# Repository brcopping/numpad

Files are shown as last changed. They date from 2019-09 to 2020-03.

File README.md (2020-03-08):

# numpad PCB
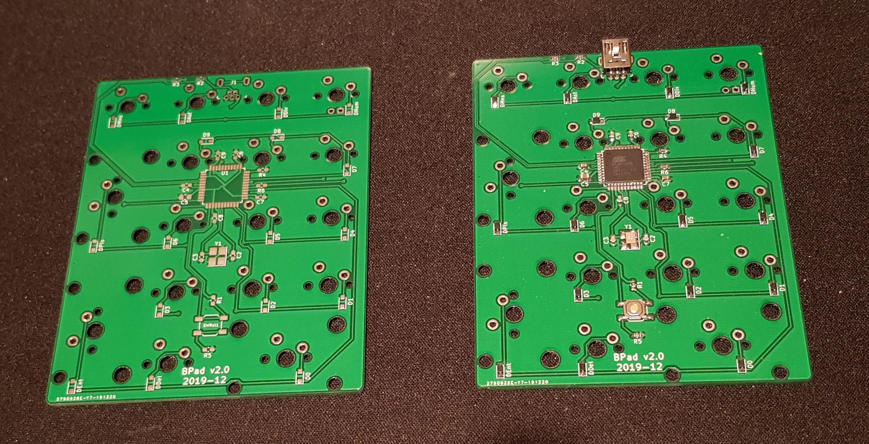
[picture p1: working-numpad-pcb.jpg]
working numpad PCB


I am following MrKeeb's and Gondolindrin's video series [PCB from Scratch with Gondo](https://youtu.be/Nk0egpDFqRA) and [ai03's guides](https://wiki.ai03.me/) to create my own numpad.

The layout is a standard numpad which can be seen here on [keyboard layout editor](http://www.keyboard-layout-editor.com/#/gists/febd745a52b943ce2c9e8b8bd37d3d38)

I created a rough case design ([main body](https://www.tinkercad.com/things/3bGqK5EBuhx) & [high profile rim](https://www.tinkercad.com/things/5EjXz9Ort4S)) for this PCB on tinkercad, it will take a [lazercut metal plate](https://github.com/brcopping/numpad/blob/master/Swill-Switch-Layer.dxf) for switch mounting. 

To hold the case together I used M3 nuts and bolts, 35mm for the back and 25mm for the front (all 4 protrude too much, so probably 33mm and 22mm would be better if attainable. Will cut mine down when i get a chance)

Numpad firmware added to [my QMK fork on git](https://github.com/brcopping/qmk_firmware). To genreate the firmware file run:
`make handwired/ben18:default`

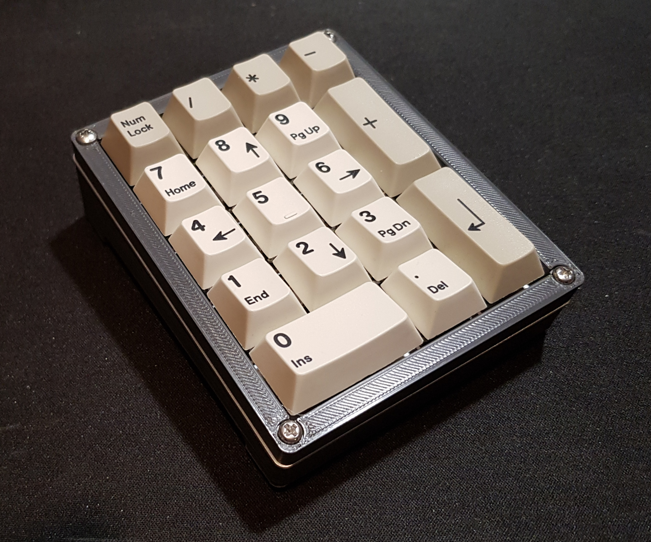
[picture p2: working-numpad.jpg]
working numpad


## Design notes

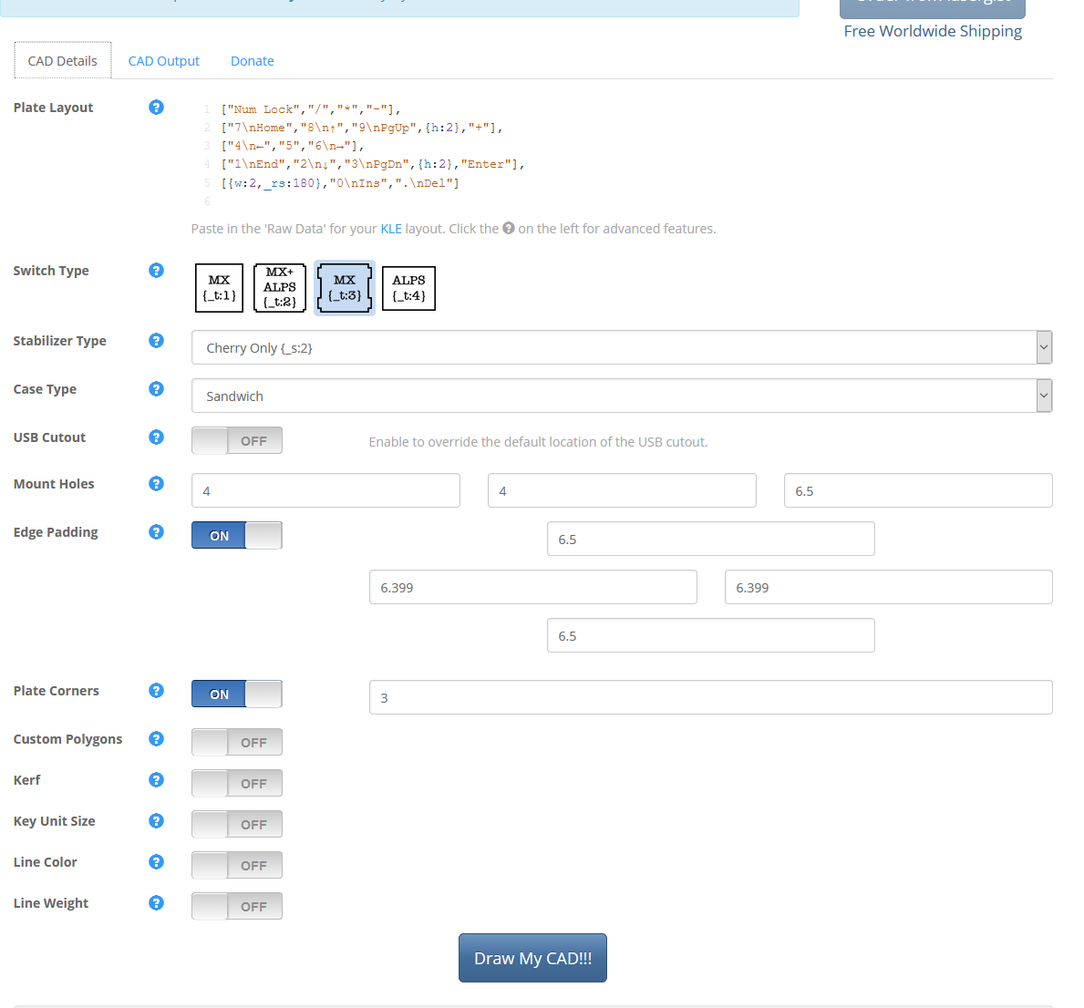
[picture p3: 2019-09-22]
Swill-Settings.PNG

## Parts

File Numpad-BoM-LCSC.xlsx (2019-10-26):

LCSC Part Number | Manufacture Part Number | Manufacturer | Customer NO. | Package | Description | RoHS | Order Qty. | Min\Mult Order Qty. | Unit Price | Order Price
C23138 | 0603WAF3300T5E | Uniroyal Elec |  | 0603 | Chip Resistor - Surface Mount 330Ohms ±1% 1/10W 0603 RoHS | Yes | 100 | 100\100 | $0.0009 | $0.09
C60580 | 1N4148WS-7-F | Diodes Incorporated |  | SOD-323 | Switching Diode 75V 150mA 1.25V @ 150mA 4ns SOD-323 RoHS | Yes | 150 | 50\50 | $0.013 | $1.95
C91701 | 0603CG220J500NT | Guangdong Fenghua Advanced Tech |  | 0603 | Multilayer Ceramic Capacitors MLCC - SMD/SMT 22pF 50V 0603 RoHS | Yes | 100 | 100\100 | $0.0028 | $0.28
C92584 | K2-1187SQ-A4SW-06 | Korean Hroparts Elec |  | SMD | Tactile Switches SPST-NO 5.20mm x 5.20mm 1.50mm 50mA @ 12VDC SMD RoHS | Yes | 10 | 10\10 | $0.0471 | $0.48
C103199 | RTT031002FTP | RALEC |  | 0603 | Chip Resistor - Surface Mount 10KOhms ±1% 1/10W 0603 RoHS | Yes | 100 | 100\100 | $0.0009 | $0.09
C119027 | 0603B104J500CT | Walsin Tech Corp |  | 0603 | Multilayer Ceramic Capacitors MLCC - SMD/SMT 100nF 50V 0603 RoHS | Yes | 50 | 50\50 | $0.0061 | $0.31
C141872 | 0603X105K500 | Walsin Tech Corp |  | 0603 | Multilayer Ceramic Capacitors MLCC - SMD/SMT 1uF 50V 0603 RoHS | Yes | 20 | 20\20 | $0.0176 | $0.36
C174301 | RS-03K22R0FT | Guangdong Fenghua Advanced Tech |  | 0603 | Chip Resistor - Surface Mount 22Ohms ±1% 1/10W 0603 RoHS | Yes | 100 | 100\100 | $0.0009 | $0.09
C280078 | M16000c516 | ZheJiang East Crystal Elec |  | SMD-3225-4P | SMD Crystal Resonators 16MHz ±10ppm SMD-3225-4P RoHS | Yes | 5 | 5\5 | $0.1155 | $0.58
C296082 | 0805X475K500CT | Walsin Tech Corp |  | 0805 | Multilayer Ceramic Capacitors MLCC - SMD/SMT 4.7uF 50V 0805 RoHS | Yes | 10 | 5\5 | $0.0647 | $0.65
C429849 | 0548190519 | MOLEX |  | Through Hole | Audio & Video Connectors Through Hole RoHS | Yes | 3 | 1\1 | $1.4621 | $4.39

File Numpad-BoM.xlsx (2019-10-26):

C2 C3 | 2 | 22pF | Capacitor_SMD:C_0603_1608Metric_Pad1.05x0.95mm_HandSolder | https://www.digikey.co.uk/product-detail/en/avx-corporation/06035A220JAT2A/478-1167-1-ND/564199
C4 | 1 | 1uF | Capacitor_SMD:C_0603_1608Metric_Pad1.05x0.95mm_HandSolder | https://www.digikey.co.uk/product-detail/en/CC0805JKX7R9BB105/311-3498-1-ND/7164519/?itemSeq=306989339 | 805
C5 | 1 | 4.7uF | Capacitor_SMD:C_0603_1608Metric_Pad1.05x0.95mm_HandSolder | https://www.digikey.co.uk/product-detail/en/samsung-electro-mechanics/CL21A475KBQNNNE/1276-1248-1-ND/3889334 | 805
C1 C8 C7 C6 C9 | 5 | 0.1uF | Capacitor_SMD:C_0603_1608Metric_Pad1.05x0.95mm_HandSolder | https://www.digikey.co.uk/product-detail/en/CL10B104JB8NNNC/1276-1033-1-ND/3889119/?itemSeq=306988917
DNum1 DDiv1 DAst1 D7 D8 D9 D4 D5 D6 D1 D2 D3 DEnt1 DDel1 D0 DMns1 DPls1 DMns2 | 18 | 1N4148W | Diode_SMD:D_SOD-323_HandSoldering | https://www.digikey.co.uk/product-detail/en/1N4148WX-TP/1N4148WXTPMSCT-ND/717312
J1 | 1 | USB_B_Mini | digikey-kicad-library:USB_Mini_B_Female_548190519 | https://www.digikey.co.uk/product-detail/en/molex/0548190519/WM17115-ND/773802
R1 R4 | 2 | 10k | Resistor_SMD:R_0603_1608Metric_Pad1.05x0.95mm_HandSolder | https://www.digikey.co.uk/product-detail/en/rohm-semiconductor/ESR03EZPF1002/RHM10KADCT-ND/1983753
R2 R3 | 2 | 22 | Resistor_SMD:R_0603_1608Metric_Pad1.05x0.95mm_HandSolder | https://www.digikey.co.uk/product-detail/en/vishay-dale/CRCW060322R0JNEAHP/541-22SACT-ND/2222801
R5 | 1 | 330 | Resistor_SMD:R_0603_1608Metric_Pad1.05x0.95mm_HandSolder | https://www.digikey.co.uk/product-detail/en/yageo/RC0603FR-07330RL/311-330HRCT-ND/730109
SW0 | 1 | 0 | AcheronMX:MX200R
SW1 | 1 | 1 | AcheronMX:MX100
SW2 | 1 | 2 | AcheronMX:MX100
SW3 | 1 | 3 | AcheronMX:MX100
SW4 | 1 | 4 | AcheronMX:MX100
SW5 | 1 | 5 | AcheronMX:MX100
SW6 | 1 | 6 | AcheronMX:MX100
SW7 | 1 | 7 | AcheronMX:MX100
SW8 | 1 | 8 | AcheronMX:MX100
SW9 | 1 | 9 | AcheronMX:MX100
SWAst1 | 1 | * | AcheronMX:MX100
SWDel1 | 1 | Del | AcheronMX:MX100
SWDiv1 | 1 | / | AcheronMX:MX100
SWEnt1 | 1 | Ent | AcheronMX:MX200VR
SWMns1 | 1 | -/Bsp | AcheronMX:MX100
SWMns2 | 1 | - | AcheronMX:MX100
SWNum1 | 1 | Num | AcheronMX:MX100
SWPls1 | 1 | + | AcheronMX:MX200VR
SWPls2 | 1 | + | AcheronMX:MX100
SWRst1 | 1 | SW_Push | AcheronHardware:smdPushBtn | https://www.digikey.co.uk/product-detail/en/PTS525SM15SMTR2+LFS/CKN9104DKR-ND/1853734/?itemSeq=306989920
U1 | 1 | ATmega32U4-AU | Package_QFP:TQFP-44_10x10mm_P0.8mm
Y1 | 1 | 16MHz | Crystal:Crystal_SMD_3225-4Pin_3.2x2.5mm_HandSoldering | https://www.digikey.co.uk/product-detail/en/ndk-america-inc/NX3225SA-16.000M-STD-CSR-1/644-1049-1-ND/1128921

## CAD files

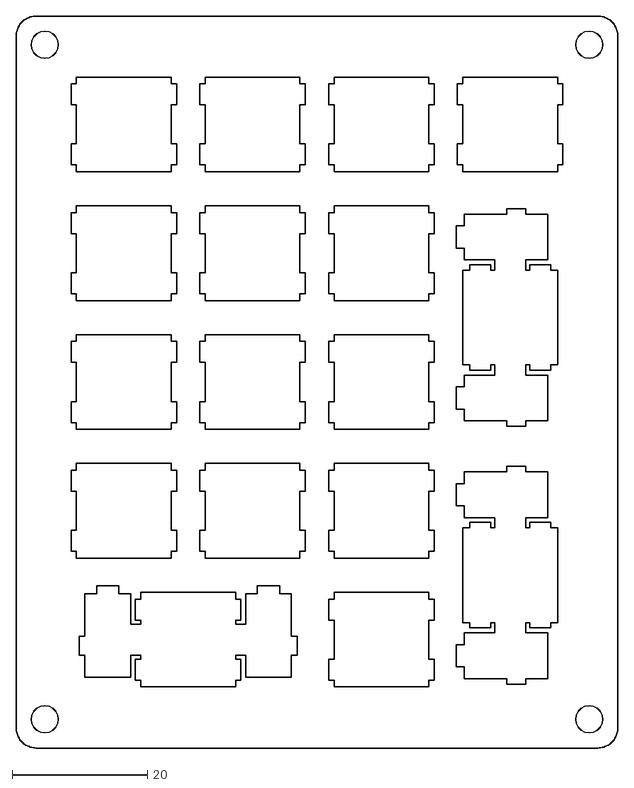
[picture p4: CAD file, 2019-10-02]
Swill-Switch-Layer.dxf
89.0 x 108.3

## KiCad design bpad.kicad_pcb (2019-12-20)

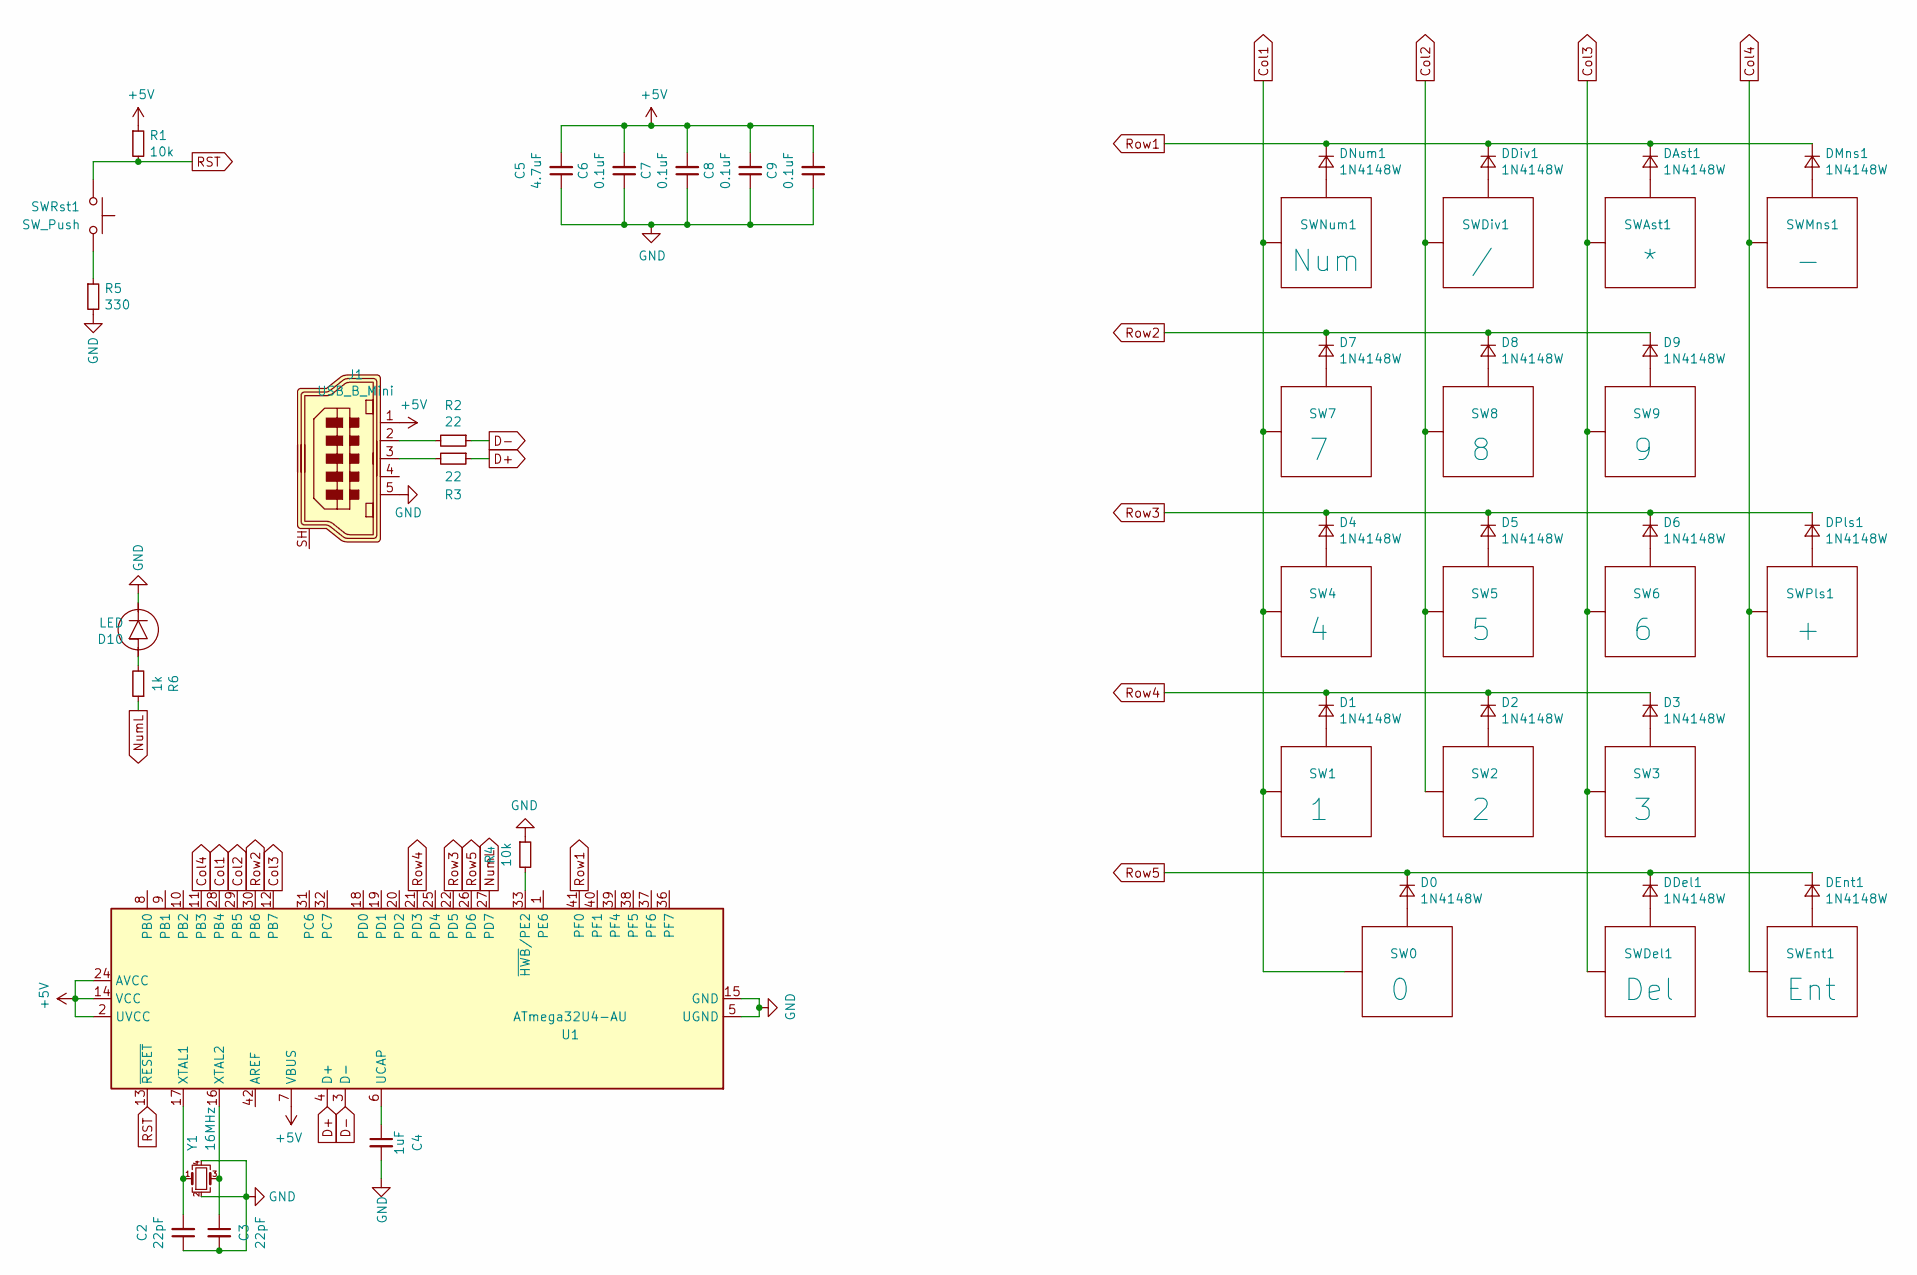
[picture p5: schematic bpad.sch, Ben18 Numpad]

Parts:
C2, C3: 22pF; C_0603_1608Metric_Pad1.05x0.95mm_HandSolder
C4: 1uF; C_0603_1608Metric_Pad1.05x0.95mm_HandSolder
C5: 4.7uF; C_0805_2012Metric_Pad1.15x1.40mm_HandSolder
C6, C7, C8, C9: 0.1uF; C_0603_1608Metric_Pad1.05x0.95mm_HandSolder
D0, D1, D2, D3, D4, D5, D6, D7, D8, D9: 1N4148W; D_SOD-323_HandSoldering
D10: LED; LED_THT_2.54mm
DAst1: 1N4148W; D_SOD-323_HandSoldering
DDel1: 1N4148W; D_SOD-323_HandSoldering
DDiv1: 1N4148W; D_SOD-323_HandSoldering
DEnt1: 1N4148W; D_SOD-323_HandSoldering
DMns1: 1N4148W; D_SOD-323_HandSoldering
DNum1: 1N4148W; D_SOD-323_HandSoldering
DPls1: 1N4148W; D_SOD-323_HandSoldering
J1: USB_B_Mini; USB_Mini_B_Female_548190519_top
R1, R4: 10k; R_0603_1608Metric_Pad1.05x0.95mm_HandSolder
R2, R3: 22; R_0603_1608Metric_Pad1.05x0.95mm_HandSolder
R5: 330; R_0603_1608Metric_Pad1.05x0.95mm_HandSolder
R6: 1k; R_0603_1608Metric_Pad1.05x0.95mm_HandSolder
SW0: 0; MX200R
SW1: 1; MX100
SW2: 2; MX100
SW3: 3; MX100
SW4: 4; MX100
SW5: 5; MX100
SW6: 6; MX100
SW7: 7; MX100
SW8: 8; MX100
SW9: 9; MX100
SWAst1: *; MX100
SWDel1: Del; MX100
SWDiv1: /; MX100
SWEnt1: Ent; MX200
SWMns1: -; MX100
SWNum1: Num; MX100
SWPls1: +; MX200
SWRst1: SW_Push; smdPushBtn
U1: ATmega32U4-AU; TQFP-44_10x10mm_P0.8mm
Y1: 16MHz; Crystal_SMD_3225-4Pin_3.2x2.5mm_HandSoldering

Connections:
+5V: C5.2, C6.2, C7.2, C8.2, C9.2, J1.1, R1.1, U1.2 (UVCC), U1.7 (VBUS), U1.14 (VCC), U1.24 (AVCC), U1.34 (VCC), U1.44 (AVCC)
Col1: SW0.1 (Col), SW1.1 (Col), SW4.1 (Col), SW7.1 (Col), SWNum1.1 (Col), U1.28 (PB4)
Col2: SW2.1 (Col), SW5.1 (Col), SW8.1 (Col), SWDiv1.1 (Col), U1.29 (PB5)
Col3: SW3.1 (Col), SW6.1 (Col), SW9.1 (Col), SWAst1.1 (Col), SWDel1.1 (Col), U1.12 (PB7)
Col4: SWEnt1.1 (Col), SWMns1.1 (Col), SWPls1.1 (Col), U1.11 (PB3)
D+: R3.1, U1.4 (D+)
D-: R2.1, U1.3 (D-)
GND: C2.1, C3.2, C4.2, C5.1, C6.1, C7.1, C8.1, C9.1, D10.K, J1.5, R4.1, R5.2, U1.5 (UGND), U1.15 (GND), U1.23 (GND), U1.35 (GND), U1.43 (GND), Y1.2, Y1.4
unnamed: C2.2, U1.17 (XTAL1), Y1.1
unnamed: C3.1, U1.16 (XTAL2), Y1.3
unnamed: C4.1, U1.6 (UCAP)
unnamed: D0.2 (A), SW0.2 (Row)
unnamed: D1.2 (A), SW1.2 (Row)
unnamed: D2.2 (A), SW2.2 (Row)
unnamed: D3.2 (A), SW3.2 (Row)
unnamed: D4.2 (A), SW4.2 (Row)
unnamed: D5.2 (A), SW5.2 (Row)
unnamed: D6.2 (A), SW6.2 (Row)
unnamed: D7.2 (A), SW7.2 (Row)
unnamed: D8.2 (A), SW8.2 (Row)
unnamed: D9.2 (A), SW9.2 (Row)
unnamed: D10.A, R6.2
unnamed: DAst1.2 (A), SWAst1.2 (Row)
unnamed 23: DDel1.2 (A), SWDel1.2 (Row); also elsewhere on the board
unnamed: DDiv1.2 (A), SWDiv1.2 (Row)
unnamed 25: DEnt1.2 (A), SWEnt1.2 (Row); also elsewhere on the board
unnamed: DMns1.2 (A), SWMns1.2 (Row)
unnamed: DNum1.2 (A), SWNum1.2 (Row)
unnamed 28: DPls1.2 (A), SWPls1.2 (Row); also elsewhere on the board
unnamed: J1.2, R2.2
unnamed: J1.3, R3.2
unnamed: R4.2, U1.33 (~HWB~/PE2)
unnamed: R5.1, SWRst1.2
NumL: R6.1, U1.27 (PD7)
RST: R1.2, SWRst1.1, U1.13 (~RESET)
Row1: DAst1.1 (K), DDiv1.1 (K), DMns1.1 (K), DNum1.1 (K), U1.41 (PF0)
Row2: D7.1 (K), D8.1 (K), D9.1 (K), U1.30 (PB6)
Row3: D4.1 (K), D5.1 (K), D6.1 (K), DPls1.1 (K), U1.22 (PD5); also elsewhere on the board
Row4: D1.1 (K), D2.1 (K), D3.1 (K), U1.21 (PD3)
Row5: D0.1 (K), DDel1.1 (K), DEnt1.1 (K), U1.26 (PD6); also elsewhere on the board

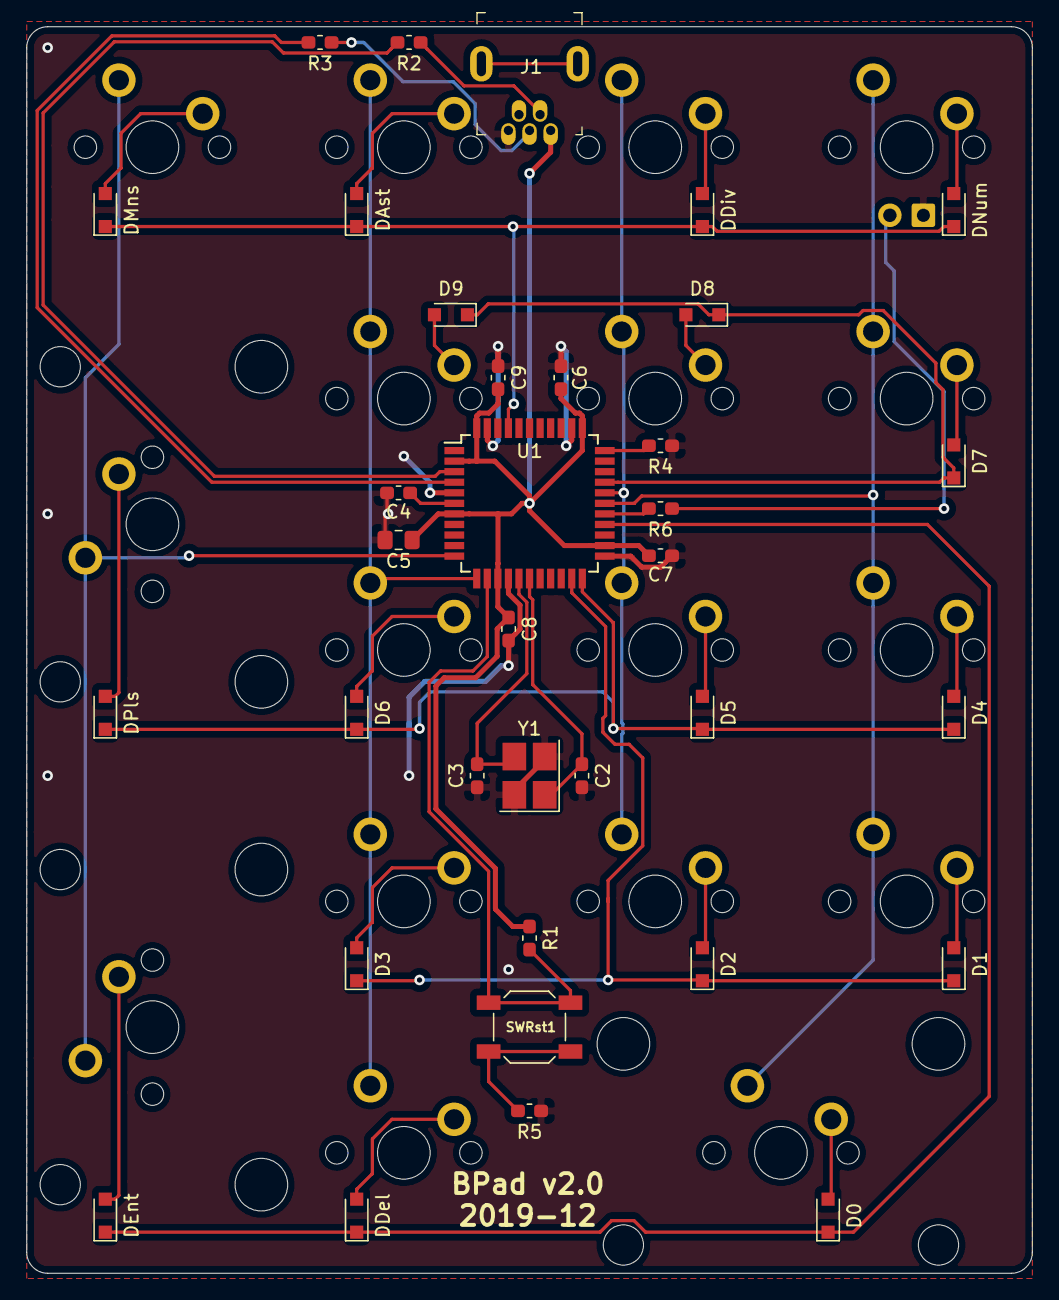
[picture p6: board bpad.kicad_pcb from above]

Board: 2 copper layers, 76.2 x 94.5 mm, 53 parts (0 on the bottom side), 40 nets.

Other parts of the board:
DDel: 1N4148W; D_SOD-323_HandSoldering
DEnt: 1N4148W; D_SOD-323_HandSoldering
DPls: 1N4148W; D_SOD-323_HandSoldering

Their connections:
unnamed 23: DDel.2; also elsewhere on the board
unnamed 25: DEnt.2; also elsewhere on the board
unnamed 28: DPls.2; also elsewhere on the board
Row3: DPls.1; also elsewhere on the board
Row5: DDel.1, DEnt.1; also elsewhere on the board

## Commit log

2019-09-07 numpad pcb design
    [Numpad.kicad_pcb, Numpad.sch]
2019-09-10 Components roughly placed in grid, connected rows and cols to processor
    [Numpad.kicad_pcb, Numpad.sch]
2019-09-13 components roughly placed
    [Numpad.kicad_pcb, Numpad.sch]
2019-09-14 ignore bak files, went bak to standard pcb orientation
    [Numpad.kicad_pcb, Numpad.sch]
2019-09-14 git ignore copied from https://github.com/github/gitignore/blob/master/KiCad.gitignore
2019-09-14 MX labels updated, missed diode spec
    [Numpad.kicad_pcb, Numpad.sch]
2019-09-14 rotated stabiliser holes for tighter pcb
    [Numpad.kicad_pcb, Numpad.sch]
2019-09-19 copied aio3's capacitor settings and fuse placement
    [Numpad.kicad_pcb, Numpad.sch]
2019-09-19 numpad name ben17
    [Numpad.kicad_pcb, Numpad.sch]
2019-09-20 moved some components around
    [Numpad.kicad_pcb, Numpad.sch]
2019-09-22 plate files added, moved around some more components
    [Numpad.kicad_pcb, Numpad.sch, Swill-Switch-Layer.dxf]
2019-10-02 added some traces, changed plate file
    [Numpad.kicad_pcb, Swill-Switch-Layer.dxf]
2019-10-06 placed clock
    [Numpad.kicad_pcb]
2019-10-13 allowed split + key
    [Numpad.kicad_pcb, Numpad.sch]
2019-10-15 all componentes withing the confines of the board now, still need to add ground. Not shure about the components around reset button or c5 & c9's grounding
    [Numpad.kicad_pcb, Numpad.sch]
2019-10-15 we can now have a maxiumum of 18 keys, so renamed it Ben18 from Ben17
    [Numpad.kicad_pcb, Numpad.sch]
2019-10-19 ground planes in, thinking about ordering
    [Numpad.kicad_pcb, Numpad.sch]
2019-10-19 two of the capacitors needed larger footprints, have added BoM
    [Numpad-BoM.xlsx, Numpad.kicad_pcb, Numpad.sch]
2019-10-26 Rotated Pls & Rtn switches, they are loose in the plate in original orientation
    [Numpad-BoM-LCSC.xlsx, Numpad-BoM.xlsx, Numpad.kicad_pcb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]
2019-11-06 ignore gerbers folder
2019-11-07 I hadnt connected the VBUS, changed it back to 17 keys no option for split plus.
    [Numpad.kicad_pcb, Numpad.sch]
2019-11-30 started again on the layout
    [Numpad.kicad_pcb, bpad.kicad_pcb, bpad.sch]
2019-12-09 moved the usb around and added label
    [bpad.kicad_pcb, bpad.sch]
2019-12-20 ordered v2
    [bpad.kicad_pcb]
2020-03-08 added image of nupad pcb
